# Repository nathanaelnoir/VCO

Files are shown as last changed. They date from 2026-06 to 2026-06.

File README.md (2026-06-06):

# AHS VCO `main_clean`

This README describes the behavior of `main_clean/main/main.ino` in musical and mathematical terms. The sketch is a three-mode Mozzi oscillator for Arduino Nano with:

- 2-operator FM mode
- chord oscillator-bank mode
- additive oscillator-bank mode

The firmware runs Mozzi in 2-pin PWM output mode with a control rate of 128 Hz. Audio generation happens in `updateAudio()`, while potentiometers, CV inputs, mode switching, oscillator frequencies, and table selections are updated in `updateControl()`.

## Inputs And Modes

The sketch reads these analog inputs:

| Name in code | Analog input | Main purpose |
| --- | ---: | --- |
| `AnalogRead0` | A0 | base pitch knob |
| `AnalogRead1` | A1 | mode-dependent parameter 1 |
| `Mode_CV` | A2 | mode CV selection |
| `AnalogRead3` | A3 | mode-dependent parameter 2 |
| `AnalogRead4` | A4 | CV for parameter 1 |
| `AnalogRead5` | A5 | CV for parameter 2 |
| `Gain_CV_*` | A6 | output level CV |
| `AnalogRead7` | A7 | V/oct input |

There are three synthesis modes:

```cpp
kModeFm       = 0
kModeChord    = 1
kModeAdditive = 2
```

The physical mode switch chooses a base ordering, and the mode CV chooses one of the three modes inside that ordering. Mathematically, the result is a discrete selector:

$$
M \in \{\mathrm{FM}, \mathrm{Chord}, \mathrm{Additive}\}
$$

where `Mode_CV` is computed by mapping the mode CV ADC value into:

$$
\mathrm{ModeCV} = \left\lfloor \mathrm{map}(A_2, 0, 1023, 0, 2) \right\rfloor
$$

The switch then permutes the three possible modes.

## Pitch Model

The sketch uses a lookup table called `voctpow`. It stores values from roughly `0` to `4.995`, indexed by the V/oct ADC input. The frequency logic repeatedly uses:

$$
f = f_\mathrm{base} \cdot 2^{V}
$$

where:

$$
V = \mathrm{voctpow}[\mathrm{ADC}]
$$

So the table is effectively a quantized exponential pitch control. If the V/oct ADC index increases by about one octave worth of table distance, the frequency doubles.

The helper:

```cpp
readVoctPow(index)
```

constrains the index to `0...1023`, then reads the floating-point value from program memory. This protects table access when chord offsets and inversion offsets are added.

## Output Level

The level CV is mapped to `0...255`:

$$
G = \mathrm{map}(A_6, 0, 1023, 0, 255)
$$

Audio samples are usually multiplied by:

$$
\frac{G}{256}
$$

Then the result is clipped to the signed 8-bit audio range:

$$
y = \mathrm{clip}(x, -128, 127)
$$

This is what `clipAudio8()` does.

## Wavetable Oscillators

The sketch uses Mozzi `Oscil` objects. Conceptually, each oscillator reads periodically through a table:

$$
x[n] = T(\phi[n])
$$

with phase:

$$
\phi[n+1] = \phi[n] + \Delta \phi
$$

where the phase increment is proportional to frequency:

$$
\Delta \phi \propto \frac{f}{f_s}
$$

Different tables give different waveforms:

| Wave enum | Table |
| --- | --- |
| `kWaveSaw` | saw |
| `kWaveSquare` | square |
| `kWaveTriangle` | triangle |
| `kWaveSine` | sine |
| `kWaveChebyshev` | Chebyshev waveshape |
| `kWaveHalfSine` | half sine |
| `kWaveSigmoid` | sigmoid waveshape |
| `kWavePhasor` | phasor |

## FM / 2-Operator Mode

FM mode uses one carrier oscillator and one modulator oscillator. In `main_clean`, both are cosine-table oscillators:

```cpp
aCarrier(COS2048_DATA)
aModulator(COS2048_DATA)
```

The base carrier frequency is computed from the pitch knob and V/oct input:

$$
f_c = (2270658 + 5000A_0) \cdot 2^V
$$

This value is a fixed-point Mozzi frequency value, not a simple Hz value. The important musical idea is:

- `A0` raises the base carrier frequency
- V/oct multiplies the frequency exponentially

The modulator frequency is derived from the carrier frequency and parameter 1:

$$
f_m \propto f_c \cdot \left(\frac{A_1}{2} + \frac{A_4}{2}\right)
$$

In code:

```cpp
mod_freq = ((carrier_freq >> 8) * (A1 / 2 + A4 / 2));
```

So parameter 1 and its CV act like a modulation-ratio or modulation-frequency control. It is not a clean integer ratio knob; it is a broad digital scaling of the carrier frequency.

The phase deviation is computed from the modulator frequency and parameter 2:

$$
D \propto f_m \cdot (1 + A_3 + A_5)
$$

In code:

```cpp
deviation = ((mod_freq >> 16) * (1 + A3 + A5));
```

The FM signal is then:

$$
y[n] = \cos\left(\phi_c[n] + D \cdot \cos(\phi_m[n])\right)
$$

scaled by the level CV:

$$
y_\mathrm{out}[n] =
\mathrm{clip}
\left(
y[n] \cdot \frac{G}{256},
-128,
127
\right)
$$

This is classic phase modulation, which is closely related to FM. The audible sidebands depend on the ratio:

$$
r = \frac{f_m}{f_c}
$$

and the modulation index/deviation:

$$
\beta \approx D
$$

For sinusoidal FM, the idealized spectrum is often described as:

$$
y(t) = \sin(2\pi f_c t + \beta \sin(2\pi f_m t))
$$

which expands into sidebands around the carrier:

$$
f = f_c \pm k f_m
$$

for integer:

$$
k = 0, 1, 2, \dots
$$

In this sketch, the scaling is fixed-point and quite aggressive, so the result is more practical/performative than mathematically normalized FM.

## Chord Mode

Chord mode creates a five-oscillator stack. Four notes come from a chord table, and the fifth oscillator repeats the root.

The chord table stores pitch offsets:

```cpp
chord_table[8][4]
```

Each row is a chord type:

| Index | Meaning |
| ---: | --- |
| 0 | major |
| 1 | major 7 |
| 2 | major add 9 |
| 3 | sus 2 |
| 4 | minor add 9 |
| 5 | minor 7 |
| 6 | minor |
| 7 | root only |

The chord selector combines the parameter 2 knob and CV:

$$
c = \mathrm{clip}
\left(
\left\lfloor \frac{A_3}{128} \right\rfloor
+
\left\lfloor \frac{A_5}{128} \right\rfloor,
0,
7
\right)
$$

The inversion selector combines parameter 1 and its CV:

$$
i = \mathrm{clip}
\left(
\left\lfloor \frac{A_1}{64} \right\rfloor
+
\left\lfloor \frac{A_4}{64} \right\rfloor,
0,
15
\right)
$$

The inversion state chooses octave shifts for the chord tones:

$$
o_1,o_2,o_3,o_4 \in \{0,1,2\}
$$

and whether the repeated root oscillator is active:

$$
r_5 \in \{0,1\}
$$

The code calls these:

```cpp
inv_aply1
inv_aply2
inv_aply3
inv_aply4
inv_aply5
```

The constant:

```cpp
kOctaveTableStep = 205
```

is the approximate table-index distance for one octave in `voctpow`. So each chord oscillator frequency is:

$$
f_j =
f_\mathrm{root}
\text{ converted through }
2^{V + \mathrm{note}_j + 205o_j}
$$

More explicitly:

$$
f_j =
f_0 \cdot
2^{
\mathrm{voctpow}
\left[
A_7 + 205o_j + n_j
\right]
}
$$

where:

- \(f_0 = A_0 / 4\)
- \(A_7\) is the V/oct ADC index
- \(o_j\) is the inversion octave offset
- \(n_j\) is the chord-table pitch offset

The fifth voice repeats the root:

$$
f_5 =
f_0 \cdot
2^{
\mathrm{voctpow}
\left[
A_7 + n_1
\right]
}
$$

but its audio is multiplied by `inv_aply5`, so it can be switched on or off:

$$
y_5[n] \cdot r_5
$$

### Chord Waveform Selection

Chord mode has selectable waveform banks. Normally parameter 1 controls inversion. But if parameter 1 is fully clockwise:

$$
A_1 \ge 1020
$$

then parameter 2 becomes a waveform selector:

$$
w = \left\lfloor \frac{A_3}{128} \right\rfloor
$$

So the 0...1023 ADC range is split into eight waveform zones.

The chord output is approximately:

$$
y[n] =
\frac{x_1[n]}{8}
+
\frac{x_2[n]}{8}
+
\frac{x_3[n]}{8}
+
\frac{x_4[n]}{8}
+
r_5\frac{x_5[n]}{8}
$$

then scaled by level:

$$
y_\mathrm{out}[n] =
\mathrm{clip}
\left(
y[n]\frac{G}{256},
-128,
127
\right)
$$

This is a parallel oscillator-bank chord. It is not additive synthesis in the Fourier sense, because the oscillators are tuned to chord intervals rather than harmonic multiples of one fundamental.

## Additive Mode

Additive mode uses eight sine oscillators:

```cpp
aSin1 ... aSin8
```

The base frequency is:

$$
f_0 = \frac{A_0}{8} \cdot 2^{\mathrm{voctpow}[A_7]}
$$

The harmonic selector is:

$$
h =
\mathrm{clip}
\left(
\left\lfloor \frac{A_3}{4} \right\rfloor
+
\left\lfloor \frac{A_5}{4} \right\rfloor,
0,
255
\right)
$$

The gain-shape selector is:

$$
g =
\mathrm{clip}
\left(
\left\lfloor \frac{A_1}{4} \right\rfloor
+
\left\lfloor \frac{A_4}{4} \right\rfloor,
0,
255
\right)
$$

The harmonic table gives integer-ish frequency multipliers:

$$
m_k(h) = \mathrm{harm\_table}[k][h]
$$

The gain table gives amplitude weights:

$$
a_k(g) = \mathrm{gain\_table}[k][g]
$$

The oscillator frequencies are:

$$
f_1 = f_0
$$

and for the other seven oscillators:

$$
f_{k+2} = f_0 \cdot m_k(h)
$$

for:

$$
k = 0,1,2,3,4,5,6
$$

The output is:

$$
y[n] =
\sum_{k=0}^{7}
\left(
\frac{a_k(g)}{1024}
\right)
\sin(2\pi f_k n / f_s)
$$

then level-scaled:

$$
y_\mathrm{out}[n] =
\mathrm{clip}
\left(
y[n]\frac{G}{256},
-128,
127
\right)
$$

### Why It Is “Kind Of Fourier” But Not Exactly

Classical additive synthesis can recreate a periodic waveform by summing harmonically related sine waves:

$$
x(t) =
\sum_{k=1}^{N}
A_k \sin(2\pi k f_0 t + \phi_k)
$$

This is close to a finite Fourier series when:

1. all partial frequencies are exact integer multiples of one fundamental,
2. amplitudes \(A_k\) represent Fourier coefficients,
3. phases \(\phi_k\) are controlled or known.

The sketch resembles this because it sums sine oscillators:

$$
y(t) =
\sum_{k=1}^{8}
A_k \sin(2\pi f_k t)
$$

However, it is not a strict Fourier reconstruction because:

- the multipliers come from `harm_table`, not from fixed \(1,2,3,4,\dots\)
- the amplitude curves come from `gain_table`, not from Fourier analysis of a target waveform
- oscillator phases are not used as explicit Fourier phase coefficients
- some multiplier combinations may create clustered, repeated, or nonstandard partial structures
- the controls are designed for musical morphing, not exact spectral reconstruction

So additive mode is better described as:

$$
\text{table-controlled partial synthesis}
$$

or:

$$
\text{a weighted sum of sine partials}
$$

rather than a mathematically exact Fourier synthesizer.

The most accurate compact description is:

$$
y(t; h,g) =
\sum_{k=1}^{8}
A_k(g)
\sin
\left(
2\pi f_0 M_k(h)t
\right)
$$

where:

- \(M_k(h)\) comes from `harm_table`
- \(A_k(g)\) comes from `gain_table`
- \(h\) controls the partial frequency structure
- \(g\) controls the partial amplitude structure

## Clipping And Scaling

All modes eventually produce an 8-bit signed audio sample. Since several oscillators are summed together, the sketch divides partials by constants such as `8` or `1024`, then applies level CV.

The final signal path is generally:

$$
y_\mathrm{digital}
=
\mathrm{clip}
\left(
\alpha \cdot
\sum_k x_k[n],
-128,
127
\right)
$$

where \(\alpha\) includes:

- per-partial scaling
- gain-table values
- level CV

This means high-gain settings can still saturate. Saturation here is not analog soft clipping; it is integer-range limiting:

$$
\mathrm{clip}(x,-128,127)
=
\begin{cases}
-128 & x < -128 \\
x & -128 \le x \le 127 \\
127 & x > 127
\end{cases}
$$

## Summary

The three modes are mathematically different.

### FM / 2-op

Core equation:

$$
y(t) = \cos\left(\phi_c + D\cos(\phi_m)\right)
$$

Musical behavior: sidebands, metallic tones, ratio/depth interaction.

### Chord

Core equation:

$$
y(t) = \sum_{j=1}^{5} x_j(t)
$$

Musical behavior: stacked chord tones from a pitch-offset table.

### Additive

Core equation:

$$
y(t) =
\sum_{k=1}^{8}
A_k(g)
\sin\left(2\pi f_0 M_k(h)t\right)
$$

Musical behavior: weighted sine partials, Fourier-like but table-shaped.

The important distinction is that chord mode sums independent musical notes, while additive mode sums partials related to one root frequency. Additive mode is Fourier-like because it is a sine sum, but it is not a true Fourier series because the frequency multipliers and amplitudes are chosen by musical lookup tables rather than derived from a target waveform.

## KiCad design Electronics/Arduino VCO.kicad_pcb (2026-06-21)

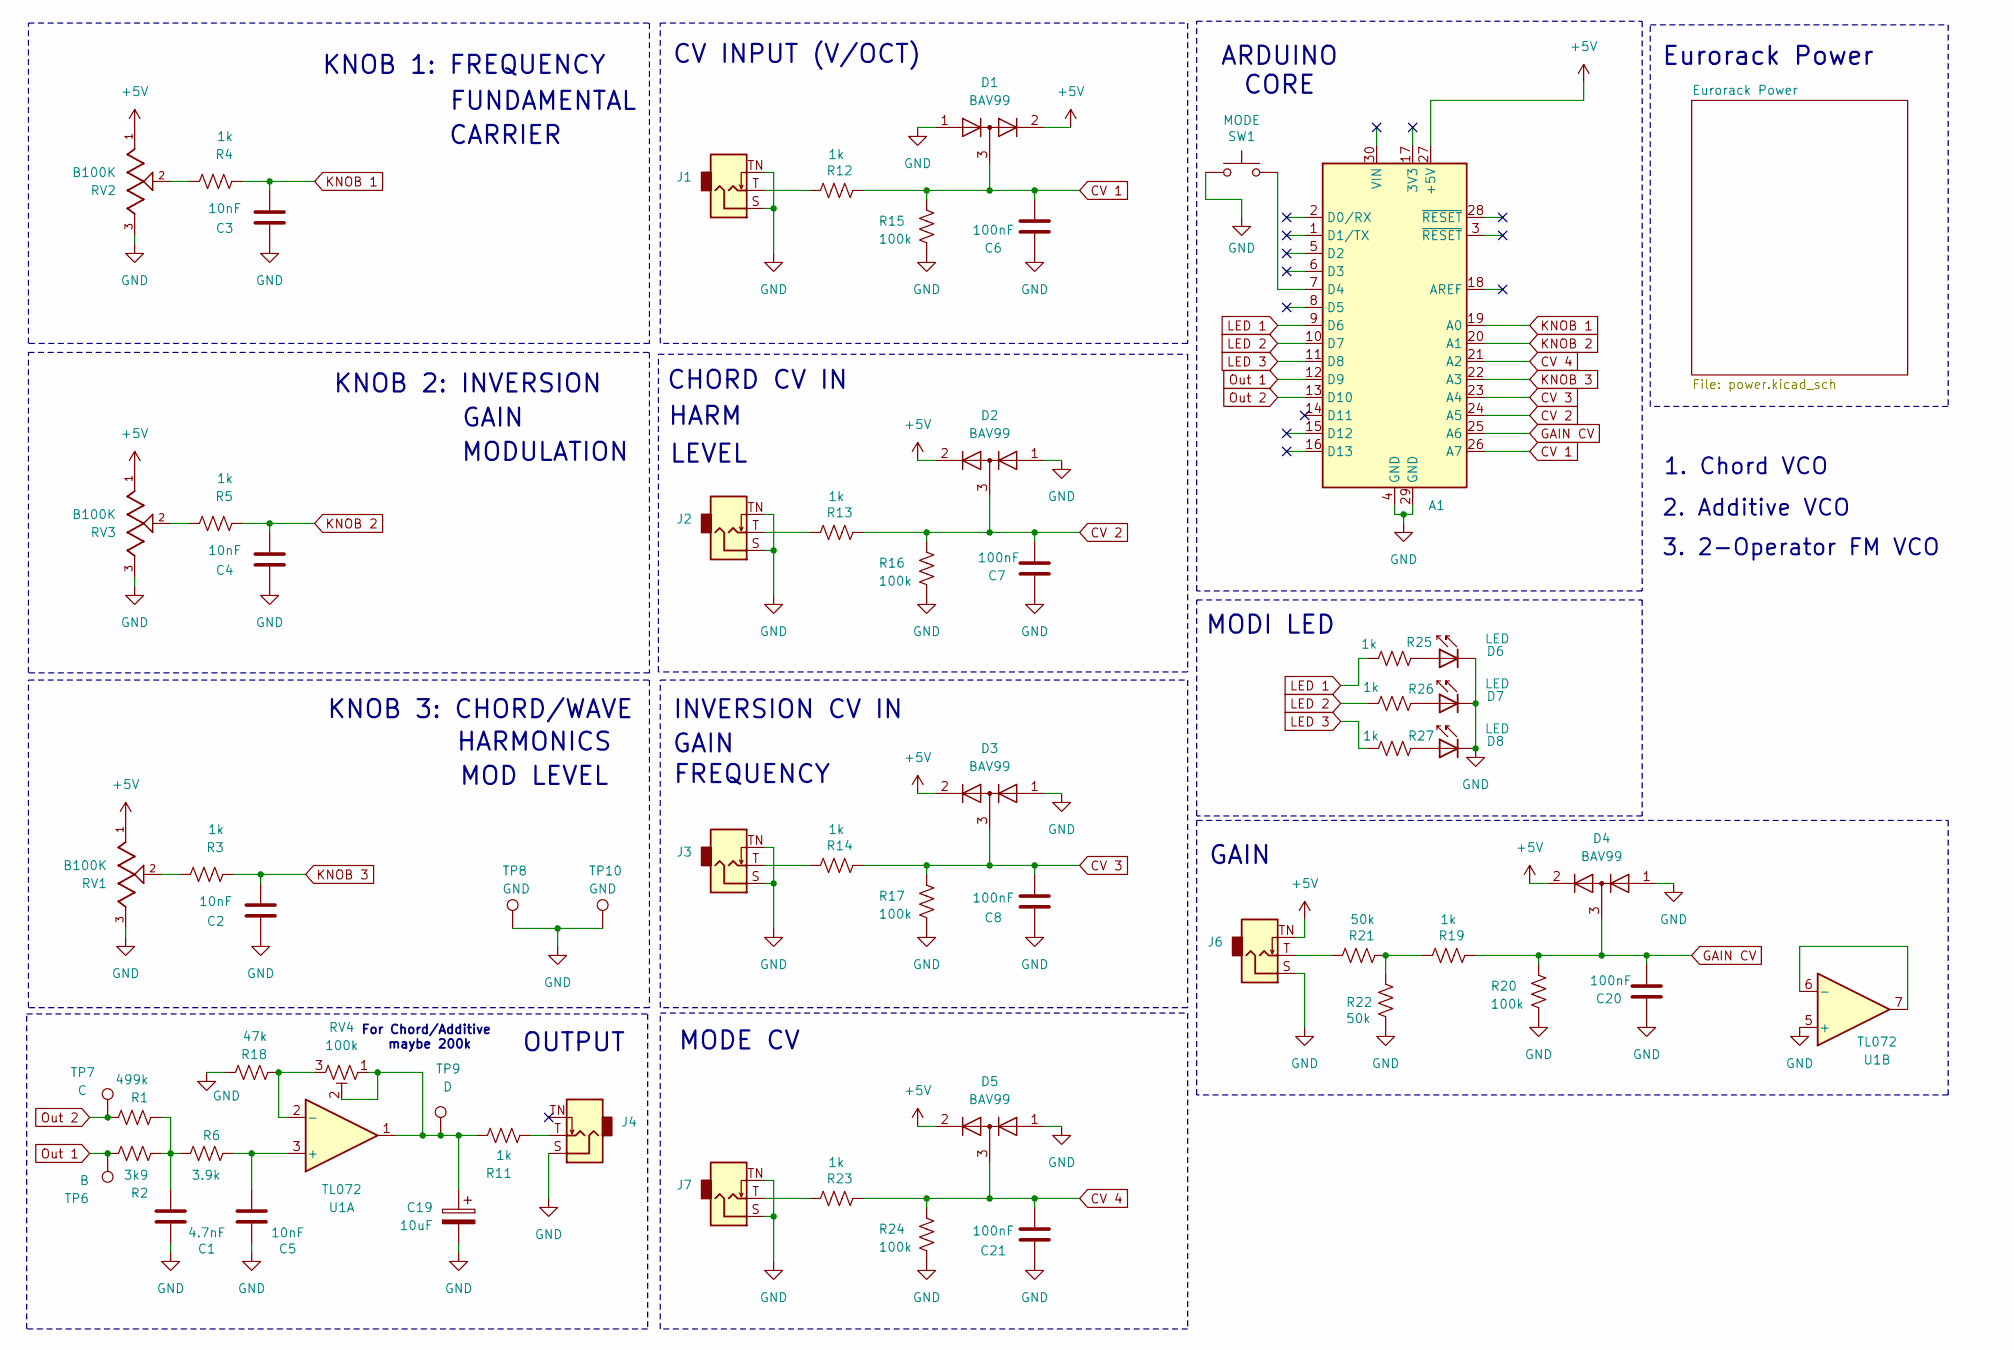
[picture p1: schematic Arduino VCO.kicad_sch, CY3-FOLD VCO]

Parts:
A1: Arduino_Nano_v3.x; Arduino_Nano
C1: 4.7nF; C_0805_2012Metric_Pad1.18x1.45mm_HandSolder
C2, C3, C4, C5: 10nF; C_0805_2012Metric_Pad1.18x1.45mm_HandSolder
C6, C7, C8, C20, C21: 100nF; C_0805_2012Metric_Pad1.18x1.45mm_HandSolder
C19: 10uF; CP_Elec_5x5.4
D1, D2, D3, D4, D5: BAV99; SOT-23
D6, D7, D8: LED; LED_D3.0mm_Clear
J1, J2, J3, J4, J6, J7: Jack_3.5mm_QingPu_WQP-PJ398SM_Vertical
R1: 499k; R_0805_2012Metric_Pad1.20x1.40mm_HandSolder
R2: 3k9; R_0805_2012Metric_Pad1.20x1.40mm_HandSolder
R3, R4, R5, R11, R12, R13, R14, R19, R23, R25, R26, R27: 1k; R_0805_2012Metric_Pad1.20x1.40mm_HandSolder
R6: 3.9k; R_0805_2012Metric_Pad1.20x1.40mm_HandSolder
R15, R16, R17, R20, R24: 100k; R_0805_2012Metric_Pad1.20x1.40mm_HandSolder
R18: 47k; R_0805_2012Metric_Pad1.20x1.40mm_HandSolder
R21, R22: 50k; R_0805_2012Metric_Pad1.20x1.40mm_HandSolder
RV1, RV2, RV3: B100K; Potentiometer_Alpha_RD901F_Vertical_Alt; PARTREV 10/5/23
RV4: 100k; Trimmer_Bourns_3296W_50k_THT
SW1: MODE; SW_PUSH_6mm_H13mm_1
TP6: B; TestPoint_Pad_D1.5mm
TP7: C; TestPoint_Pad_D1.5mm
TP8, TP10: GND; TestPoint_Pad_D1.5mm
TP9: D; TestPoint_Pad_D1.5mm
U1: TL072; SOIC-8_3.9x4.9mm_P1.27mm

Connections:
+5V: A1.27 (+5V), D1.2 (A), D2.2 (A), D3.2 (A), D4.2 (A), D5.2 (A), J6.TN, RV1.1, RV2.1, RV3.1; also elsewhere on the board
CV 1: A1.26 (A7), C6.2, D1.3 (K), R12.2, R15.2
CV 2: A1.24 (A5), C7.2, D2.3 (K), R13.2, R16.2
CV 3: A1.23 (A4), C8.2, D3.3 (K), R14.2, R17.2
CV 4: A1.21 (A2), C21.2, D5.3 (K), R23.2, R24.2
GAIN CV: A1.25 (A6), C20.2, D4.3 (K), R19.2, R20.2
GND: A1.4 (GND), A1.29 (GND), C1.2, C2.1, C3.1, C4.1, C5.2, C6.1, C7.1, C8.1, C19.2, C20.1, C21.1, D1.1 (K), D2.1 (K), D3.1 (K), D4.1 (K), D5.1 (K), D6.1 (K), D7.1 (K), D8.1 (K), J1.S, J1.TN, J2.S, J2.TN, J3.S, J3.TN, J4.S, J6.S, J7.S, J7.TN, R15.1, R16.1, R17.1, R18.1, R20.1, R22.1, R24.1, RV1.3, RV2.3, RV3.3, SW1.1, TP8.1 (1_1), TP10.1, U1.5 (+); also elsewhere on the board
KNOB 1: A1.19 (A0), C3.2, R4.2
KNOB 2: A1.20 (A1), C4.2, R5.2
KNOB 3: A1.22 (A3), C2.2, R3.2
LED 1: A1.9 (D6), R25.1
LED 2: A1.10 (D7), R26.1
LED 3: A1.11 (D8), R27.1
unnamed: A1.7 (D4), SW1.2
unnamed: C1.1, R1.2, R2.2, R6.1
unnamed 17: C19.1, R11.1, RV4.1, RV4.2, TP9.1, U1.1; also elsewhere on the board
unnamed: D6.2 (A), R25.2
unnamed: D7.2 (A), R26.2
unnamed: D8.2 (A), R27.2
unnamed: J1.T, R12.1
unnamed: J2.T, R13.1
unnamed: J3.T, R14.1
unnamed: J4.T, R11.2
unnamed: J6.T, R21.1
unnamed: J7.T, R23.1
unnamed: R3.1, RV1.2
unnamed: R4.1, RV2.2
unnamed: R5.1, RV3.2
unnamed: R19.1, R21.2, R22.2
unnamed: C5.1, R6.2, U1.3 (+)
unnamed: R18.2, RV4.3, U1.2 (-)
unnamed: U1.6 (-), U1.7
Out 1: A1.12 (D9), R2.1, TP6.1; also elsewhere on the board
Out 2: A1.13 (D10), R1.1, TP7.1; also elsewhere on the board

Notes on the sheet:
CHORD CV IN
HARMONICS
MODI LED
For Chord/Additive maybe 200k
FREQUENCY
CV INPUT (V/OCT)
KNOB 1: FREQUENCY
FUNDAMENTAL
KNOB 3: CHORD/WAVE
MOD LEVEL
ARDUINO CORE
2. Additive VCO
KNOB 2: INVERSION
3. 2-Operator FM VCO
Eurorack Power
GAIN
OUTPUT
1. Chord VCO
CARRIER
INVERSION CV IN
LEVEL
MODE CV
MODULATION
HARM

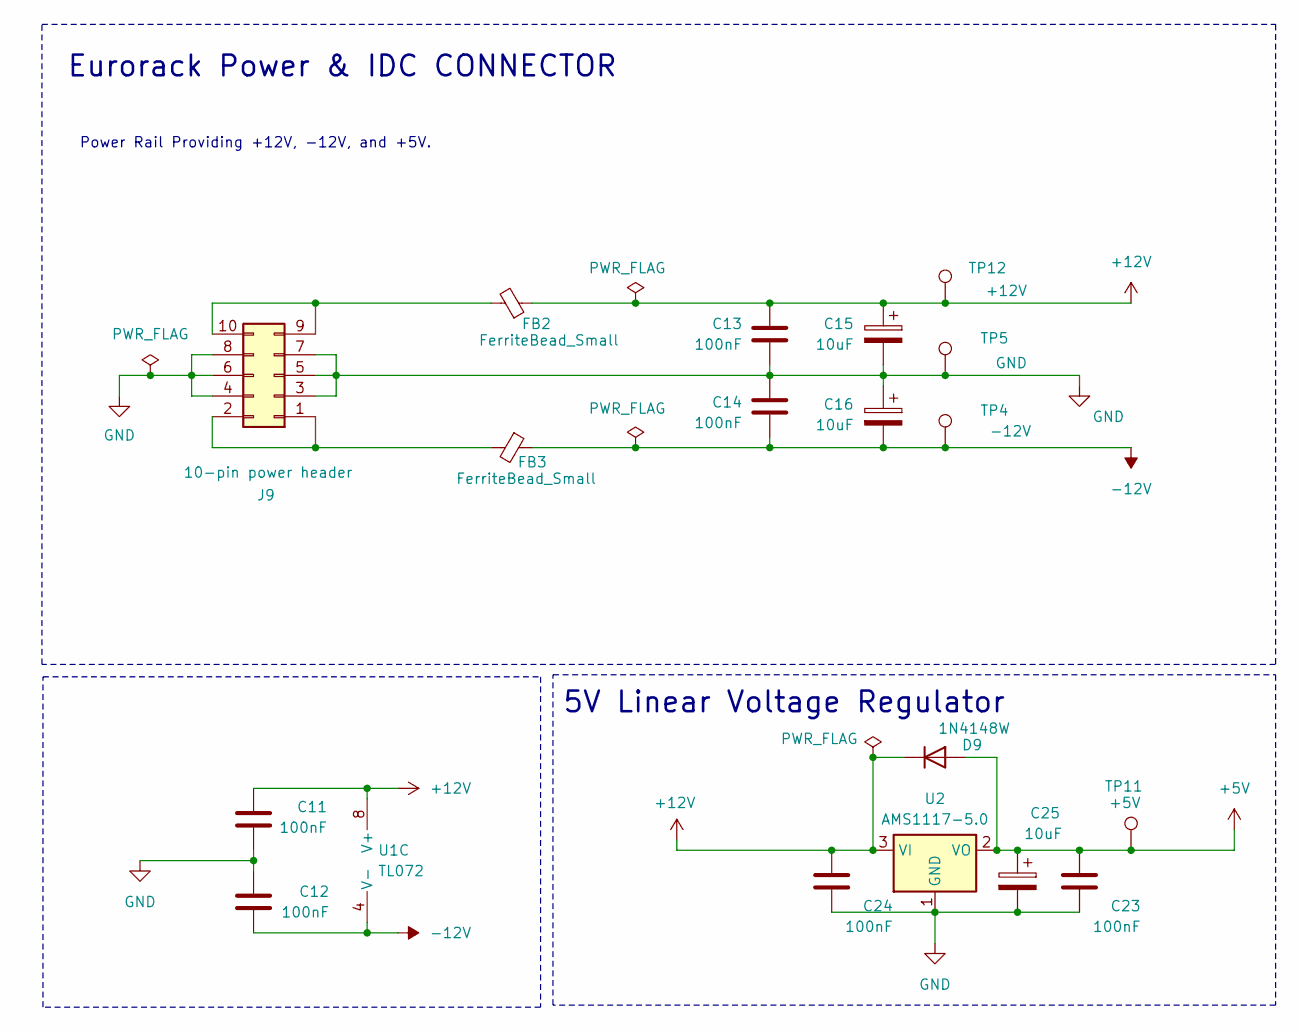
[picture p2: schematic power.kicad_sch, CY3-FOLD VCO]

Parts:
C11, C12, C13, C14, C23, C24: 100nF; C_0805_2012Metric_Pad1.18x1.45mm_HandSolder
C15, C16, C25: 10uF; CP_Elec_5x5.4
D9: 1N4148W; D_SOD-123
FB2, FB3: FerriteBead_Small; L_0805_2012Metric_Pad1.05x1.20mm_HandSolder
J9: 10-pin power header; IDC-Header_2x05_P2.54mm_Vertical
TP4: -12V; TestPoint_Pad_D1.5mm
TP5: GND; TestPoint_Pad_D1.5mm
TP11: +5V; TestPoint_Pad_D1.5mm
TP12: +12V; TestPoint_Pad_D1.5mm
U1: TL072; SOIC-8_3.9x4.9mm_P1.27mm
U2: AMS1117-5.0; SOT-223-3_TabPin2

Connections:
+5V: C23.1, C25.1, D9.2 (A), TP11.1, U2.2 (VO); also elsewhere on the board
+12V: C11.1, C13.1, C15.1, C24.1, D9.1 (K), FB2.1, U1.8 (V+), U2.3 (VI); also elsewhere on the board
-12V: C12.2, C14.2, C16.2, FB3.1, TP4.1 (1_1), U1.4 (V-)
GND: C11.2, C12.1, C13.2, C14.1, C15.2, C16.1, C23.2, C24.2, C25.2, J9.3, J9.4, J9.5, J9.6, J9.7, J9.8, TP5.1 (1_1), U2.1 (GND); also elsewhere on the board
unnamed: FB3.2, J9.1, J9.2
unnamed: FB2.2, J9.9, J9.10

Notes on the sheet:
Power Rail Providing +12V, -12V, and +5V.
Eurorack Power & IDC CONNECTOR
5V Linear Voltage Regulator

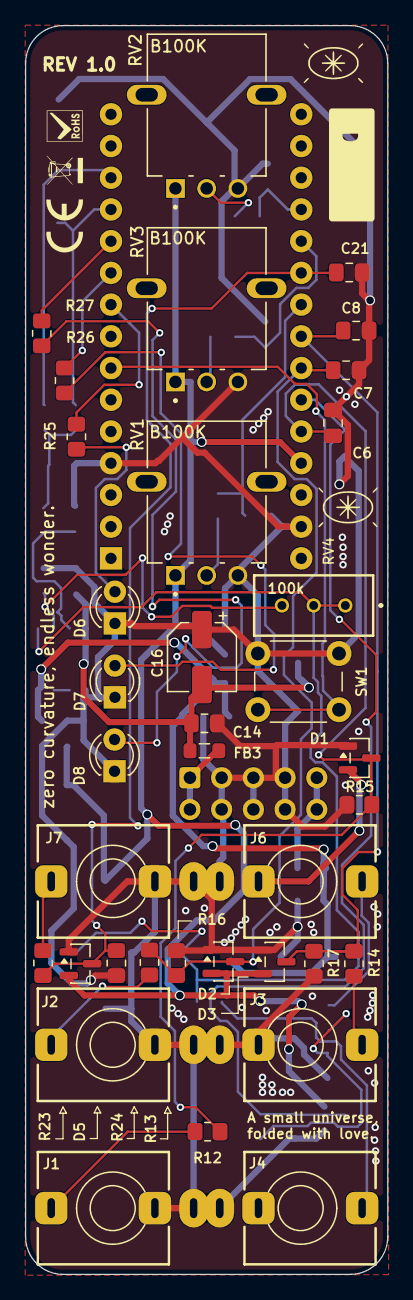
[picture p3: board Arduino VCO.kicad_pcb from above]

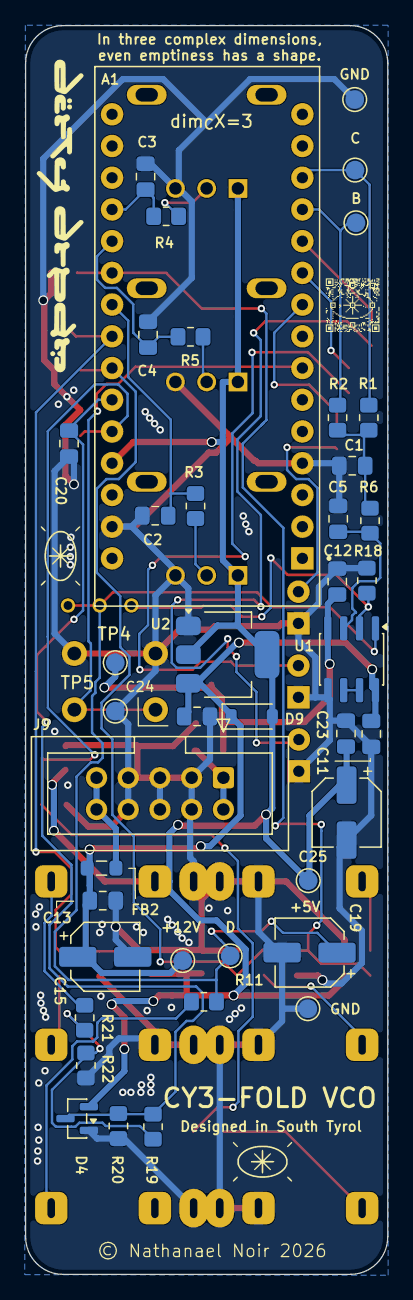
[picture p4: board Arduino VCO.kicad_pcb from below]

Board: 2 copper layers, 29.0 x 100.0 mm, 78 parts (42 on the bottom side), 38 nets.

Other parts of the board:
+5V: +5V; TestPoint_Pad_D1.5mm
+12V: +12V; TestPoint_Pad_D1.5mm
B: B; TestPoint_Pad_D1.5mm
C: C; TestPoint_Pad_D1.5mm
D: D; TestPoint_Pad_D1.5mm
GND: GND; TestPoint_Pad_D1.5mm

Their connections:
+5V: +5V.1 (1_1); also elsewhere on the board
+12V: +12V.1 (1_1); also elsewhere on the board
GND: GND.1 (1_1); also elsewhere on the board
unnamed 17: D.1 (1_1); also elsewhere on the board
Out 1: B.1 (1_1); also elsewhere on the board
Out 2: C.1 (1_1); also elsewhere on the board

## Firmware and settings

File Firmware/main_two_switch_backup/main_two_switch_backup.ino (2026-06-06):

/*
  AHS VCO firmware, Mozzi v2.0.4 / Arduino Nano

  This sketch keeps the original three-mode voice architecture:
    - FM voice
    - chord oscillator bank
    - additive sine bank

  Mozzi v2 reads audio configuration from these inline defines before
  <Mozzi.h>, so the library's MozziConfig.h file must stay untouched.
*/

#include <MozziConfigValues.h>
#define MOZZI_AUDIO_MODE MOZZI_OUTPUT_2PIN_PWM
#define MOZZI_CONTROL_RATE 128
#include <Mozzi.h>
#include <Oscil.h>
#include <mozzi_fixmath.h>


#include <tables/sin2048_int8.h>

#include <tables/cos2048_int8.h>

#include <tables/saw2048_int8.h>
#include <tables/square_no_alias512_int8.h>
#include <tables/triangle_hermes_2048_int8.h>
#include <tables/waveshape_chebyshev_3rd_256_int8.h>
#include <tables/halfsin256_uint8.h>
#include <tables/waveshape_sigmoid_int8.h>
#include <tables/phasor256_int8.h>


constexpr byte kFmLedPin = 7;
constexpr byte kChordLedPin = 6;
constexpr byte kAdditiveLedPin = 8;
constexpr byte kModeSwitchLeftPin = 5;
constexpr byte kModeSwitchRightPin = 4;

constexpr byte kPitchPotInput = 0;
constexpr byte kParam1MainInput = 1;
constexpr byte kModeCvInput = 2;
constexpr byte kParam2MainInput = 3;
constexpr byte kParam1CvInput = 4;
constexpr byte kParam2CvInput = 5;
constexpr byte kLevelCvInput = 6;
constexpr byte kVoctInput = 7;

constexpr int kAdcMax = 1023;
constexpr int kAudio8Min = -128;
constexpr int kAudio8Max = 127;
constexpr int kWaveSelectThreshold = 1020;
constexpr int kOctaveTableStep = 205;

enum SynthMode : byte {
 kModeFm = 0,
 kModeChord = 1,
 kModeAdditive = 2,
};

enum ChordWave : byte {
 kWaveSaw = 0,
 kWaveSquare = 1,
 kWaveTriangle = 2,
 kWaveSine = 3,
 kWaveChebyshev = 4,
 kWaveHalfSine = 5,
 kWaveSigmoid = 6,
 kWavePhasor = 7,
};






Oscil <SIN2048_NUM_CELLS, MOZZI_AUDIO_RATE> aSin1(SIN2048_DATA);
Oscil <SIN2048_NUM_CELLS, MOZZI_AUDIO_RATE> aSin2(SIN2048_DATA);
Oscil <SIN2048_NUM_CELLS, MOZZI_AUDIO_RATE> aSin3(SIN2048_DATA);
Oscil <SIN2048_NUM_CELLS, MOZZI_AUDIO_RATE> aSin4(SIN2048_DATA);
Oscil <SIN2048_NUM_CELLS, MOZZI_AUDIO_RATE> aSin5(SIN2048_DATA);
Oscil <SIN2048_NUM_CELLS, MOZZI_AUDIO_RATE> aSin6(SIN2048_DATA);
Oscil <SIN2048_NUM_CELLS, MOZZI_AUDIO_RATE> aSin7(SIN2048_DATA);
Oscil <SIN2048_NUM_CELLS, MOZZI_AUDIO_RATE> aSin8(SIN2048_DATA);





Oscil<COS2048_NUM_CELLS, MOZZI_AUDIO_RATE> aCarrier(COS2048_DATA);
Oscil<COS2048_NUM_CELLS, MOZZI_AUDIO_RATE> aModulator(COS2048_DATA);
Oscil<COS2048_NUM_CELLS, MOZZI_CONTROL_RATE> kModIndex(COS2048_DATA);





Oscil <SAW2048_NUM_CELLS, MOZZI_AUDIO_RATE> aSaw1(SAW2048_DATA);
Oscil <SAW2048_NUM_CELLS, MOZZI_AUDIO_RATE> aSaw2(SAW2048_DATA);
Oscil <SAW2048_NUM_CELLS, MOZZI_AUDIO_RATE> aSaw3(SAW2048_DATA);
Oscil <SAW2048_NUM_CELLS, MOZZI_AUDIO_RATE> aSaw4(SAW2048_DATA);
Oscil <SAW2048_NUM_CELLS, MOZZI_AUDIO_RATE> aSaw5(SAW2048_DATA);

Oscil <SQUARE_NO_ALIAS512_NUM_CELLS, MOZZI_AUDIO_RATE> aSqu1(SQUARE_NO_ALIAS512_DATA);
Oscil <SQUARE_NO_ALIAS512_NUM_CELLS, MOZZI_AUDIO_RATE> aSqu2(SQUARE_NO_ALIAS512_DATA);
Oscil <SQUARE_NO_ALIAS512_NUM_CELLS, MOZZI_AUDIO_RATE> aSqu3(SQUARE_NO_ALIAS512_DATA);
Oscil <SQUARE_NO_ALIAS512_NUM_CELLS, MOZZI_AUDIO_RATE> aSqu4(SQUARE_NO_ALIAS512_DATA);
Oscil <SQUARE_NO_ALIAS512_NUM_CELLS, MOZZI_AUDIO_RATE> aSqu5(SQUARE_NO_ALIAS512_DATA);

Oscil <TRIANGLE_HERMES_2048_NUM_CELLS, MOZZI_AUDIO_RATE> aTri1(TRIANGLE_HERMES_2048_DATA);
Oscil <TRIANGLE_HERMES_2048_NUM_CELLS, MOZZI_AUDIO_RATE> aTri2(TRIANGLE_HERMES_2048_DATA);
Oscil <TRIANGLE_HERMES_2048_NUM_CELLS, MOZZI_AUDIO_RATE> aTri3(TRIANGLE_HERMES_2048_DATA);
Oscil <TRIANGLE_HERMES_2048_NUM_CELLS, MOZZI_AUDIO_RATE> aTri4(TRIANGLE_HERMES_2048_DATA);
Oscil <TRIANGLE_HERMES_2048_NUM_CELLS, MOZZI_AUDIO_RATE> aTri5(TRIANGLE_HERMES_2048_DATA);

Oscil <CHEBYSHEV_3RD_256_NUM_CELLS, MOZZI_AUDIO_RATE> aChb1(CHEBYSHEV_3RD_256_DATA);
Oscil <CHEBYSHEV_3RD_256_NUM_CELLS, MOZZI_AUDIO_RATE> aChb2(CHEBYSHEV_3RD_256_DATA);
Oscil <CHEBYSHEV_3RD_256_NUM_CELLS, MOZZI_AUDIO_RATE> aChb3(CHEBYSHEV_3RD_256_DATA);
Oscil <CHEBYSHEV_3RD_256_NUM_CELLS, MOZZI_AUDIO_RATE> aChb4(CHEBYSHEV_3RD_256_DATA);
Oscil <CHEBYSHEV_3RD_256_NUM_CELLS, MOZZI_AUDIO_RATE> aChb5(CHEBYSHEV_3RD_256_DATA);

Oscil <HALFSIN256_NUM_CELLS, MOZZI_AUDIO_RATE> ahSin1(HALFSIN256_DATA);
Oscil <HALFSIN256_NUM_CELLS, MOZZI_AUDIO_RATE> ahSin2(HALFSIN256_DATA);
Oscil <HALFSIN256_NUM_CELLS, MOZZI_AUDIO_RATE> ahSin3(HALFSIN256_DATA);
Oscil <HALFSIN256_NUM_CELLS, MOZZI_AUDIO_RATE> ahSin4(HALFSIN256_DATA);
Oscil <HALFSIN256_NUM_CELLS, MOZZI_AUDIO_RATE> ahSin5(HALFSIN256_DATA);

Oscil <WAVESHAPE_SIGMOID_NUM_CELLS, MOZZI_AUDIO_RATE> aSig1(WAVESHAPE_SIGMOID_DATA);
Oscil <WAVESHAPE_SIGMOID_NUM_CELLS, MOZZI_AUDIO_RATE> aSig2(WAVESHAPE_SIGMOID_DATA);
Oscil <WAVESHAPE_SIGMOID_NUM_CELLS, MOZZI_AUDIO_RATE> aSig3(WAVESHAPE_SIGMOID_DATA);
Oscil <WAVESHAPE_SIGMOID_NUM_CELLS, MOZZI_AUDIO_RATE> aSig4(WAVESHAPE_SIGMOID_DATA);
Oscil <WAVESHAPE_SIGMOID_NUM_CELLS, MOZZI_AUDIO_RATE> aSig5(WAVESHAPE_SIGMOID_DATA);

Oscil <PHASOR256_NUM_CELLS, MOZZI_AUDIO_RATE> aPha1(PHASOR256_DATA);
Oscil <PHASOR256_NUM_CELLS, MOZZI_AUDIO_RATE> aPha2(PHASOR256_DATA);
Oscil <PHASOR256_NUM_CELLS, MOZZI_AUDIO_RATE> aPha3(PHASOR256_DATA);
Oscil <PHASOR256_NUM_CELLS, MOZZI_AUDIO_RATE> aPha4(PHASOR256_DATA);
Oscil <PHASOR256_NUM_CELLS, MOZZI_AUDIO_RATE> aPha5(PHASOR256_DATA);





// These names mirror the original sketch so the musical behavior is easy to
// compare while debugging against the older file.
int freq1 = 110;
int voct = 1000;
int voct2 = 1000;


int AnalogRead0 = 0;
int AnalogRead1 = 0;
int AnalogRead3 = 0;
int AnalogRead4 = 0;
int AnalogRead5 = 0;
int AnalogRead7 = 0;


int freqv1 = 440;
int freqv2 = 440;
int freqv3 = 440;
int freqv4 = 440;
int freqv5 = 440;


byte note1 = 0;
byte note2 = 0;
byte note3 = 0;
byte note4 = 0;
byte note5 = 0;

byte inv_aply1 = 0;
byte inv_aply2 = 0;
byte inv_aply3 = 0;
byte inv_aply4 = 0;
bool inv_aply5 = 0;

int inv = 0;
int inv_knob = 0;
int chord = 0;
byte wave = kWaveSaw;



int harm_knob = 0;
byte gain = 127;
byte additive_gain_1 = 0;
byte additive_gain_2 = 0;
byte additive_gain_3 = 0;
byte additive_gain_4 = 0;
byte additive_gain_5 = 0;
byte additive_gain_6 = 0;
byte additive_gain_7 = 0;
byte additive_gain_8 = 0;

int Switch = 0;
int Mode = 0;
int Mode_CV = 0;
int Gain_CV_0 = 0;
int Gain_CV_1 = 0;
int Gain_CV_2 = 0;



const static byte chord_table[8][4]PROGMEM = {
 {  0,  68, 119,  205,  },//Maj
 { 0,  68, 119,  187,  },//Maj7
 { 0,  68, 119,  239,  },//Majadd9
 { 0,  34, 119,  205,  },//sus2
 { 0,  51, 119,  239,  },//minadd9
 { 0,  51, 119,  170,  },//min7
 { 0,  51, 119,  205,  },//min
 { 0,  0,  0,  0,  }//root
};


const static float voctpow[1024] PROGMEM = {
 0,  0.004882, 0.009765, 0.014648, 0.019531, 0.024414, 0.029296, 0.034179, 0.039062, 0.043945, 0.048828, 0.05371,  0.058593, 0.063476, 0.068359, 0.073242, 0.078125, 0.083007, 0.08789,  0.092773, 0.097656, 0.102539, 0.107421, 0.112304, 0.117187, 0.12207,  0.126953, 0.131835, 0.136718, 0.141601, 0.146484, 0.151367, 0.15625,  0.161132, 0.166015, 0.170898, 0.175781, 0.180664, 0.185546, 0.190429, 0.195312, 0.200195, 0.205078, 0.20996,  0.214843, 0.219726, 0.224609, 0.229492, 0.234375, 0.239257, 0.24414,  0.249023, 0.253906, 0.258789, 0.263671, 0.268554, 0.273437, 0.27832,  0.283203, 0.288085, 0.292968, 0.297851, 0.302734, 0.307617, 0.3125, 0.317382, 0.322265, 0.327148, 0.332031, 0.336914, 0.341796, 0.346679, 0.351562, 0.356445, 0.361328, 0.36621,  0.371093, 0.375976, 0.380859, 0.385742, 0.390625, 0.395507, 0.40039,  0.405273, 0.410156, 0.415039, 0.419921, 0.424804, 0.429687, 0.43457,  0.439453, 0.444335, 0.449218, 0.454101, 0.458984, 0.463867, 0.46875,  0.473632, 0.478515, 0.483398, 0.488281, 0.493164, 0.498046, 0.502929, 0.507812, 0.512695, 0.517578, 0.52246,  0.527343, 0.532226, 0.537109, 0.541992, 0.546875, 0.551757, 0.55664,  0.561523, 0.566406, 0.571289, 0.576171, 0.581054, 0.585937, 0.59082,  0.595703, 0.600585, 0.605468, 0.610351, 0.615234, 0.620117, 0.625,  0.629882, 0.634765, 0.639648, 0.644531, 0.649414, 0.654296, 0.659179, 0.664062, 0.668945, 0.673828, 0.67871,  0.683593, 0.688476, 0.693359, 0.698242, 0.703125, 0.708007, 0.71289,  0.717773, 0.722656, 0.727539, 0.732421, 0.737304, 0.742187, 0.74707,  0.751953, 0.756835, 0.761718, 0.766601, 0.771484, 0.776367, 0.78125,  0.786132, 0.791015, 0.795898, 0.800781, 0.805664, 0.810546, 0.815429, 0.820312, 0.825195, 0.830078, 0.83496,  0.839843, 0.844726, 0.849609, 0.854492, 0.859375, 0.864257, 0.86914,  0.874023, 0.878906, 0.883789, 0.888671, 0.893554, 0.898437, 0.90332,  0.908203, 0.913085, 0.917968, 0.922851, 0.927734, 0.932617, 0.9375, 0.942382, 0.947265, 0.952148, 0.957031, 0.961914, 0.966796, 0.971679, 0.976562, 0.981445, 0.986328, 0.99121,  0.996093, 1.000976, 1.005859, 1.010742, 1.015625, 1.020507, 1.02539,  1.030273, 1.035156, 1.040039, 1.044921, 1.049804, 1.054687, 1.05957,  1.064453, 1.069335, 1.074218, 1.079101, 1.083984, 1.088867, 1.09375,  1.098632, 1.103515, 1.108398, 1.113281, 1.118164, 1.123046, 1.127929, 1.132812, 1.137695, 1.142578, 1.14746,  1.152343, 1.157226, 1.162109, 1.166992, 1.171875, 1.176757, 1.18164,  1.186523, 1.191406, 1.196289, 1.201171, 1.206054, 1.210937, 1.21582,  1.220703, 1.225585, 1.230468, 1.235351, 1.240234, 1.245117, 1.25, 1.254882, 1.259765, 1.264648, 1.269531, 1.274414, 1.279296, 1.284179, 1.289062, 1.293945, 1.298828, 1.30371,  1.308593, 1.313476, 1.318359, 1.323242, 1.328125, 1.333007, 1.33789,  1.342773, 1.347656, 1.352539, 1.357421, 1.362304, 1.367187, 1.37207,  1.376953, 1.381835, 1.386718, 1.391601, 1.396484, 1.401367, 1.40625,  1.411132, 1.416015, 1.420898, 1.425781, 1.430664, 1.435546, 1.440429, 1.445312, 1.450195, 1.455078, 1.45996,  1.464843, 1.469726, 1.474609, 1.479492, 1.484375, 1.489257, 1.49414,  1.499023, 1.503906, 1.508789, 1.513671, 1.518554, 1.523437, 1.52832,  1.533203, 1.538085, 1.542968, 1.547851, 1.552734, 1.557617, 1.5625, 1.567382, 1.572265, 1.577148, 1.582031, 1.586914, 1.591796, 1.596679, 1.601562, 1.606445, 1.611328, 1.61621,  1.621093, 1.625976, 1.630859, 1.635742, 1.640625, 1.645507, 1.65039,  1.655273, 1.660156, 1.665039, 1.669921, 1.674804, 1.679687, 1.68457,  1.689453, 1.694335, 1.699218, 1.704101, 1.708984, 1.713867, 1.71875,  1.723632, 1.728515, 1.733398, 1.738281, 1.743164, 1.748046, 1.752929, 1.757812, 1.762695, 1.767578, 1.77246,  1.777343, 1.782226, 1.787109, 1.791992, 1.796875, 1.801757, 1.80664,  1.811523, 1.816406, 1.821289, 1.826171, 1.831054, 1.835937, 1.84082,  1.845703, 1.850585, 1.855468, 1.860351, 1.865234, 1.870117, 1.875,  1.879882, 1.884765, 1.889648, 1.894531, 1.899414, 1.904296, 1.909179, 1.914062, 1.918945, 1.923828, 1.92871,  1.933593, 1.938476, 1.943359, 1.948242, 1.953125, 1.958007, 1.96289,  1.967773, 1.972656, 1.977539, 1.982421, 1.987304, 1.992187, 1.99707,  2.001953, 2.006835, 2.011718, 2.016601, 2.021484, 2.026367, 2.03125,  2.036132, 2.041015, 2.045898, 2.050781, 2.055664, 2.060546, 2.065429, 2.070312, 2.075195, 2.080078, 2.08496,  2.089843, 2.094726, 2.099609, 2.104492, 2.109375, 2.114257, 2.11914,  2.124023, 2.128906, 2.133789, 2.138671, 2.143554, 2.148437, 2.15332,  2.158203, 2.163085, 2.167968, 2.172851, 2.177734, 2.182617, 2.1875, 2.192382, 2.197265, 2.202148, 2.207031, 2.211914, 2.216796, 2.221679, 2.226562, 2.231445, 2.236328, 2.24121,  2.246093, 2.250976, 2.255859, 2.260742, 2.265625, 2.270507, 2.27539,  2.280273, 2.285156, 2.290039, 2.294921, 2.299804, 2.304687, 2.30957,  2.314453, 2.319335, 2.324218, 2.329101, 2.333984, 2.338867, 2.34375,  2.348632, 2.353515, 2.358398, 2.363281, 2.368164, 2.373046, 2.377929, 2.382812, 2.387695, 2.392578, 2.39746,  2.402343, 2.407226, 2.412109, 2.416992, 2.421875, 2.426757, 2.43164,  2.436523, 2.441406, 2.446289, 2.451171, 2.456054, 2.460937, 2.46582,  2.470703, 2.475585, 2.480468, 2.485351, 2.490234, 2.495117, 2.5,  2.504882, 2.509765, 2.514648, 2.519531, 2.524414, 2.529296, 2.534179, 2.539062, 2.543945, 2.548828, 2.55371,  2.558593, 2.563476, 2.568359, 2.573242, 2.578125, 2.583007, 2.58789,  2.592773, 2.597656, 2.602539, 2.607421, 2.612304, 2.617187, 2.62207,  2.626953, 2.631835, 2.636718, 2.641601, 2.646484, 2.651367, 2.65625,  2.661132, 2.666015, 2.670898, 2.675781, 2.680664, 2.685546, 2.690429, 2.695312, 2.700195, 2.705078, 2.70996,  2.714843, 2.719726, 2.724609, 2.729492, 2.734375, 2.739257, 2.74414,  2.749023, 2.753906, 2.758789, 2.763671, 2.768554, 2.773437, 2.77832,  2.783203, 2.788085, 2.792968, 2.797851, 2.802734, 2.807617, 2.8125, 2.817382, 2.822265, 2.827148, 2.832031, 2.836914, 2.841796, 2.846679, 2.851562, 2.856445, 2.861328, 2.86621,  2.871093, 2.875976, 2.880859, 2.885742, 2.890625, 2.895507, 2.90039,  2.905273, 2.910156, 2.915039, 2.919921, 2.924804, 2.929687, 2.93457,  2.939453, 2.944335, 2.949218, 2.954101, 2.958984, 2.963867, 2.96875,  2.973632, 2.978515, 2.983398, 2.988281, 2.993164, 2.998046, 3.002929, 3.007812, 3.012695, 3.017578, 3.02246,  3.027343, 3.032226, 3.037109, 3.041992, 3.046875, 3.051757, 3.05664,  3.061523, 3.066406, 3.071289, 3.076171, 3.081054, 3.085937, 3.09082,  3.095703, 3.100585, 3.105468, 3.110351, 3.115234, 3.120117, 3.125,  3.129882, 3.134765, 3.139648, 3.144531, 3.149414, 3.154296, 3.159179, 3.164062, 3.168945, 3.173828, 3.17871,  3.183593, 3.188476, 3.193359, 3.198242, 3.203125, 3.208007, 3.21289,  3.217773, 3.222656, 3.227539, 3.232421, 3.237304, 3.242187, 3.24707,  3.251953, 3.256835, 3.261718, 3.266601, 3.271484, 3.276367, 3.28125,  3.286132, 3.291015, 3.295898, 3.300781, 3.305664, 3.310546, 3.315429, 3.320312, 3.325195, 3.330078, 3.33496,  3.339843, 3.344726, 3.349609, 3.354492, 3.359375, 3.364257, 3.36914,  3.374023, 3.378906, 3.383789, 3.388671, 3.393554, 3.398437, 3.40332,  3.408203, 3.413085, 3.417968, 3.422851, 3.427734, 3.432617, 3.4375, 3.442382, 3.447265, 3.452148, 3.457031, 3.461914, 3.466796, 3.471679, 3.476562, 3.481445, 3.486328, 3.49121,  3.496093, 3.500976, 3.505859, 3.510742, 3.515625, 3.520507, 3.52539,  3.530273, 3.535156, 3.540039, 3.544921, 3.549804, 3.554687, 3.55957,  3.564453, 3.569335, 3.574218, 3.579101, 3.583984, 3.588867, 3.59375,  3.598632, 3.603515, 3.608398, 3.613281, 3.618164, 3.623046, 3.627929, 3.632812, 3.637695, 3.642578, 3.64746,  3.652343, 3.657226, 3.662109, 3.666992, 3.671875, 3.676757, 3.68164,  3.686523, 3.691406, 3.696289, 3.701171, 3.706054, 3.710937, 3.71582,  3.720703, 3.725585, 3.730468, 3.735351, 3.740234, 3.745117, 3.75, 3.754882, 3.759765, 3.764648, 3.769531, 3.774414, 3.779296, 3.784179, 3.789062, 3.793945, 3.798828, 3.80371,  3.808593, 3.813476, 3.818359, 3.823242, 3.828125, 3.833007, 3.83789,  3.842773, 3.847656, 3.852539, 3.857421, 3.862304, 3.867187, 3.87207,  3.876953, 3.881835, 3.886718, 3.891601, 3.896484, 3.901367, 3.90625,  3.911132, 3.916015, 3.920898, 3.925781, 3.930664, 3.935546, 3.940429, 3.945312, 3.950195, 3.955078, 3.95996,  3.964843, 3.969726, 3.974609, 3.979492, 3.984375, 3.989257, 3.99414,  3.999023, 4.003906, 4.008789, 4.013671, 4.018554, 4.023437, 4.02832,  4.033203, 4.038085, 4.042968, 4.047851, 4.052734, 4.057617, 4.0625, 4.067382, 4.072265, 4.077148, 4.082031, 4.086914, 4.091796, 4.096679, 4.101562, 4.106445, 4.111328, 4.11621,  4.121093, 4.125976, 4.130859, 4.135742, 4.140625, 4.145507, 4.15039,  4.155273, 4.160156, 4.165039, 4.169921, 4.174804, 4.179687, 4.18457,  4.189453, 4.194335, 4.199218, 4.204101, 4.208984, 4.213867, 4.21875,  4.223632, 4.228515, 4.233398, 4.238281, 4.243164, 4.248046, 4.252929, 4.257812, 4.262695, 4.267578, 4.27246,  4.277343, 4.282226, 4.287109, 4.291992, 4.296875, 4.301757, 4.30664,  4.311523, 4.316406, 4.321289, 4.326171, 4.331054, 4.335937, 4.34082,  4.345703, 4.350585, 4.355468, 4.360351, 4.365234, 4.370117, 4.375,  4.379882, 4.384765, 4.389648, 4.394531, 4.399414, 4.404296, 4.409179, 4.414062, 4.418945, 4.423828, 4.42871,  4.433593, 4.438476, 4.443359, 4.448242, 4.453125, 4.458007, 4.46289,  4.467773, 4.472656, 4.477539, 4.482421, 4.487304, 4.492187, 4.49707,  4.501953, 4.506835, 4.511718, 4.516601, 4.521484, 4.526367, 4.53125,  4.536132, 4.541015, 4.545898, 4.550781, 4.555664, 4.560546, 4.565429, 4.570312, 4.575195, 4.580078, 4.58496,  4.589843, 4.594726, 4.599609, 4.604492, 4.609375, 4.614257, 4.61914,  4.624023, 4.628906, 4.633789, 4.638671, 4.643554, 4.648437, 4.65332,  4.658203, 4.663085, 4.667968, 4.672851, 4.677734, 4.682617, 4.6875, 4.692382, 4.697265, 4.702148, 4.707031, 4.711914, 4.716796, 4.721679, 4.726562, 4.731445, 4.736328, 4.74121,  4.746093, 4.750976, 4.755859, 4.760742, 4.765625, 4.770507, 4.77539,  4.780273, 4.785156, 4.790039, 4.794921, 4.799804, 4.804687, 4.80957,  4.814453, 4.819335, 4.824218, 4.829101, 4.833984, 4.838867, 4.84375,  4.848632, 4.853515, 4.858398, 4.863281, 4.868164, 4.873046, 4.877929, 4.882812, 4.887695, 4.892578, 4.89746,  4.902343, 4.907226, 4.912109, 4.916992, 4.921875, 4.926757, 4.93164,  4.936523, 4.941406, 4.946289, 4.951171, 4.956054, 4.960937, 4.96582,  4.970703, 4.975585, 4.980468, 4.985351, 4.990234, 4.995117
};
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
void loop() {
 audioHook(); // required here

 
}

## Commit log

2026-04-15 changing the schematic template
2026-04-15 making schematics more agnostic to arduino code
    [Arduino VCO.kicad_sch, power.kicad_sch]
2026-04-15 renaming the global pins
    [Arduino VCO.kicad_sch]
2026-04-15 adding values to caps
    [Arduino VCO.kicad_sch, power.kicad_sch]
2026-04-15 ordering the footprint nummeration
    [Arduino VCO.kicad_sch]
2026-04-16 changing layout
    [Arduino VCO.kicad_sch]
2026-04-17 deleting the plot
    [Arduino VCO.kicad_sch, power.kicad_sch]
2026-04-18 adding a comment for potental problem
    [Arduino VCO.kicad_sch]
2026-04-21 optimized main_v1 reference
    [Arduino VCO.kicad_sch]
2026-04-22 adding further testpoints
    [Arduino VCO.kicad_sch, power.kicad_sch, vco.kicad_pcb]
2026-04-23 leaving a remark of the firmwares on the schematics
    [Arduino VCO.kicad_pcb, Arduino VCO.kicad_sch, power.kicad_sch]
2026-06-06 Fix formatting in README.md and add VCO schematic files
    - Updated mathematical notation in README.md to use \mathrm{} for consistency.
    - Added new KiCad project file for VCO schematic (vco.kicad_prl).
    - Created a lock file for the KiCad project to track user session information.
    [Arduino VCO.kicad_sch]
2026-06-07 Add font configuration file for KiCad CLI reports
    This commit introduces a new `fonts.conf` file to specify font directories and cache location for the KiCad CLI reports. The configuration includes standard system font directories as well as a user-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
    [Arduino VCO.kicad_pcb, Arduino VCO.kicad_sch, power.kicad_sch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]
2026-06-16 starting pcb
    [Arduino VCO.kicad_pcb, Arduino VCO.kicad_sch, power.kicad_sch]
2026-06-17 changing tracks
    [Arduino VCO.kicad_pcb]
2026-06-20 finishing tracks and resolving drc errors
    [Arduino VCO.kicad_pcb, Arduino VCO.kicad_sch]
2026-06-21 Adding Silkscreen symbols
    [Arduino VCO.kicad_pcb, Arduino VCO.kicad_sch, power.kicad_sch]
2026-06-21 changing silkscreen letter size
    [Arduino VCO.kicad_pcb]

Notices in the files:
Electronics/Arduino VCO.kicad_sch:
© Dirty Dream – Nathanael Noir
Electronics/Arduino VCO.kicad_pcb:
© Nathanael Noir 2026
